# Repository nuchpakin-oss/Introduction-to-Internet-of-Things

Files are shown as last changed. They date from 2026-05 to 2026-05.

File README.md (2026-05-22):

# Introduction to Internet of Things (IoT)

โปรเจกต์นี้เป็นระบบ IoT สำหรับตรวจวัดสภาพแวดล้อมภายในห้องแบบเรียลไทม์ โดยใช้บอร์ด **ESP32** เชื่อมต่อกับเซนเซอร์ต่าง ๆ เพื่อเก็บข้อมูลและตรวจจับการเคลื่อนไหว จากนั้นสามารถนำข้อมูลไปแสดงผลหรือประยุกต์ใช้กับระบบ Smart Home ได้

## Features

* ตรวจวัดอุณหภูมิและความชื้นด้วยเซนเซอร์ DHT
* ตรวจจับการเคลื่อนไหวด้วย PIR Motion Sensor
* ตรวจจับความเข้มแสงด้วย LDR Sensor
* ใช้ RGB LED แสดงสถานะของระบบ
* ประมวลผลและควบคุมด้วย ESP32
* รองรับการพัฒนาต่อยอดสู่ระบบ IoT ผ่าน Wi-Fi

## Components Used

* ESP32 DevKit V1
* DHT11/DHT22 Sensor
* PIR Motion Sensor
* LDR Sensor
* RGB LED
* Resistors
* Breadboard & Jumper Wires

## System Overview

ระบบจะทำการอ่านค่าจากเซนเซอร์ต่าง ๆ เช่น อุณหภูมิ ความชื้น แสง และการเคลื่อนไหว แล้วส่งข้อมูลเข้าสู่ ESP32 เพื่อประมวลผล โดยสามารถแสดงสถานะผ่าน RGB LED หรือส่งข้อมูลไปยังแพลตฟอร์ม IoT สำหรับการติดตามแบบออนไลน์ได้

## Applications

* Smart Room Monitoring
* Smart Home System
* ระบบแจ้งเตือนการเคลื่อนไหว
* ระบบตรวจสอบสภาพแวดล้อมภายในอาคาร

## Circuit Diagram

ตัวอย่างการเชื่อมต่ออุปกรณ์ในโปรเจกต์



NodeRED_Dashboard

InfluxDB

Blynk_Dashboard

Blynk_Dashboard_mobile

Telegram_Alert

## Future Improvements

* เพิ่มการแสดงผลผ่าน Web Dashboard
* บันทึกข้อมูลลง Cloud Database
* แจ้งเตือนผ่าน LINE Notify หรือ Telegram
* ควบคุมอุปกรณ์ผ่าน Mobile Application

## Author

Developed for learning and experimentation in Internet of Things (IoT).

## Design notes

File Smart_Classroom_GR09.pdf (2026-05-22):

I o T P R O J E C T

# Smart Classroom Focus Monitor

## ระบบ IoT ส ำหรับตรวจสอบควำมพรอ้ มของหอ้ งเรยีน ด ้วย Edge AI + Cloud Dashboard

DHT22 | LDR | PIR | Node-RED | InfluxDB | Blynk | ThingSpeak
Smart Classroom Focus Monitor | 1

# ปัญหาและแนวคิด

### เหตุผลที่น ำ IoT มำใชใ้นหอ้ งเรยีน

## ปัญหาที่พบ

### สภาพห้องไม่เหมาะสม

ห ้องเรียนอำจร ้อน มืด หรอื ไมม่ คี นใชง้ำนแตย่ งัเปิดระบบไว ้

### ผู้ดูแลไม่เห็นสภาพ real-time

ผู้สอน/ผู้ดูแลไม่สำมำรถติดตำมสภำพห ้องเมื่ออยู่นอกห ้องได ้

### ขาดข้อมูลย้อนหล ังเพื่อปร ับปรุง

ไมม่ ขี อ้ มลู ชว่ ยวเิครำะหช์ ว่ งเวลำทสี่ ภำพหอ้ งไมเ่ หมำะสม

### แนวคิดหล ัก

### ตรวจสภาพห้อง → วิเคราะห์ความพร้อม

### → แจ้งเตือน → ควบคุมอ ัตโนม ัติ

ระบบท ำงำนวนซำ ้ เพอื่ ปรับสภำพหอ้ งใหเ้หมำะสมเสมอ

## ข ั้นตอนการท างาน

1

## Monitor — ตรวจว ัดสภาพห้อง

เซ็นเซอรเ์ก็บขอ้มลู real-time: อุณหภูมิแสง ควำมชนื้ กำร เคลื่อนไหว

2

## Analyze — วิเคราะห์ความพร้อม

ประมวลผลข ้อมูลเทียบค่ำมำตรฐำน หำควำมผิดปกติของ สภำพห ้อง

3

## Alert — แจ้งเตือนผู้สอน/ผู้ดูแล

สง่ แจง้เตอืนผำ่ นแอปหรอื dashboard เมื่อพบสภำพไม่ เหมำะสม

4

## Control — ควบคุมอุปกรณ์อ ัตโนม ัติ

สงั่ เปิด/ปิดแอร์ไฟ พัดลม ตำมเงื่อนไข เพื่อประหยัดพลังงำน

# ว ัตถุประสงค์ของระบบ

### เป้ำหมำยที่สอดคล ้องกับเกณฑ์กำรประเมิน

## เป้ าหมายหล ัก 5 ประการ

### 1 อ่ำนค่ำอุณหภูมิควำมชนื้ แสง และกำรมีคนในห ้อง

### 2 ค ำนวณ Focus Score ประเมินควำมเหมำะสมต่อกำรเรียน

### 3 เก็บข ้อมูลลง Time Series DB และแสดงกรำฟย ้อนหลัง

### 4 ควบคุม RGB LED, Buzzer และ Servo ทั้ง local/remote

### 5 แจ ้งเตือนผ่ำน Telegram เมื่อสภำพห ้องผิดปกติ

## ครอบคลุม 4 ดา้นส าคญั

### Local Dashboard

แสดงค่ำและควบคุมจำก
Node-RED Dashboard

### Remote Cloud

ดูข ้อมูลจำกภำยนอกผ่ำน
Blynk + ThingSpeak

### Edge AI

ค ำนวณ Focus Score + ตรวจ
anomaly ที่ Edge

### Notification

สง่ แจง้เตอืนผำ่ น Telegram bot

อป
ุ

# กรณท

์ ใี่
ช

้

### Sensors ≥ 2 และ Actuators ≥ 2 ตำมโจทย์

### SENSORS — ร ับข้อมูลจากสภาพแวดล้อม

## DHT22

Temperature / Humidity
วดั อณุ หภมู แิละควำมชนื้ ในหอ้ ง

## LDR / GY-302

Light
วัดควำมสว่ำงของแสงในห ้อง

## PIR

Motion
ตรวจจับกำรเคลื่อนไหวของคน

### ACTUATORS — ตอบสนองตามคา สง่ั

## RGB LED

Status Indicator
แสดงสถำนะห ้อง: เขียว/เหลือง/แดง

## Buzzer

Local Alert
สง่ เสยี งเตอื นเมอื่ พบควำมผดิ ปกติ

## Servo

Curtain Demo
จ ำลองกำรเปิด/ปิดม่ำนอัตโนมัติ

# Wiring Summary

### กำรต่อวงจรของ ESP32 กับเซน็ เซอรแ์ ละ Actuators

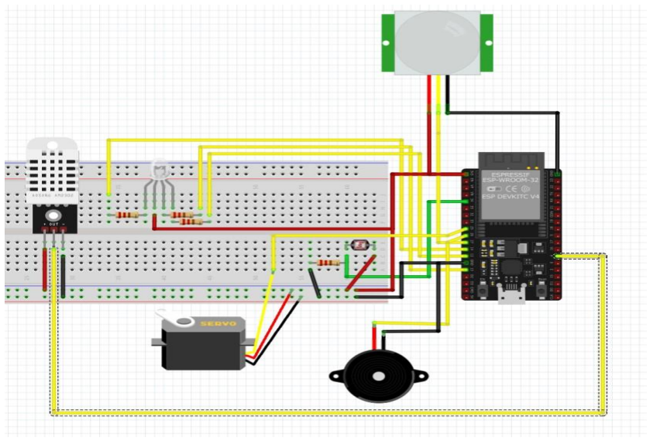
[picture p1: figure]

## การเชอื่ มตอ่ หลกั

DHT22 | GPIO 4
LDR | GPIO 34 (ADC)
PIR | GPIO 27
RGB LED | GPIO 25, 26, 33
Buzzer | GPIO 13
Servo | GPIO 14 (PWM)

ใช ้breadboard เป็ นจุดรวมกำรต่อสำย และต่อตัวต ้ำนทำนให ้ RGB LED ทุกขำ เพอื่ ป้องกนั ควำมเสยีหำย

# System Architecture

### Sensor → Edge → Database → AI → UI/Cloud → Actuator

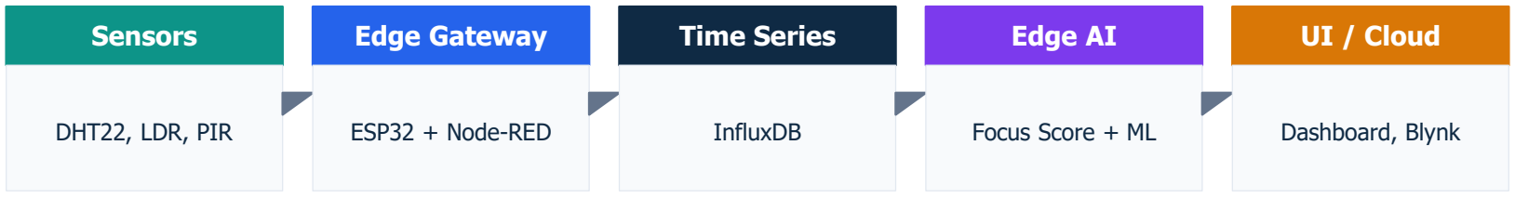
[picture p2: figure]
Sensors; DHT22, LDR, PIR; Edge Gateway; ESP32 + Node-RED; Time Series; InfluxDB; Edge AI; Focus Score + ML; UI / Cloud; Dashboard, Blynk

## Actuators: LED + Buzzer + Servo

การไหลของข้อมูล
ESP32 อ่ำนค่ำ sensor → สง่ ผำ่ น MQTT ไปยัง Node-RED → ประมวลผล Edge AI ค ำนวณ Focus Score → บันทึกลง InfluxDB และสง่ ตอ่ Dashboard/Cloud → สง่ ค ำสงั่ กลบั ไปควบคมุ Actuators

# Flowchart การท างาน

### ล ำดับขนั้ หลักของระบบตัง้แตร่ ับขอ้มลู ถงึสง่ ออก

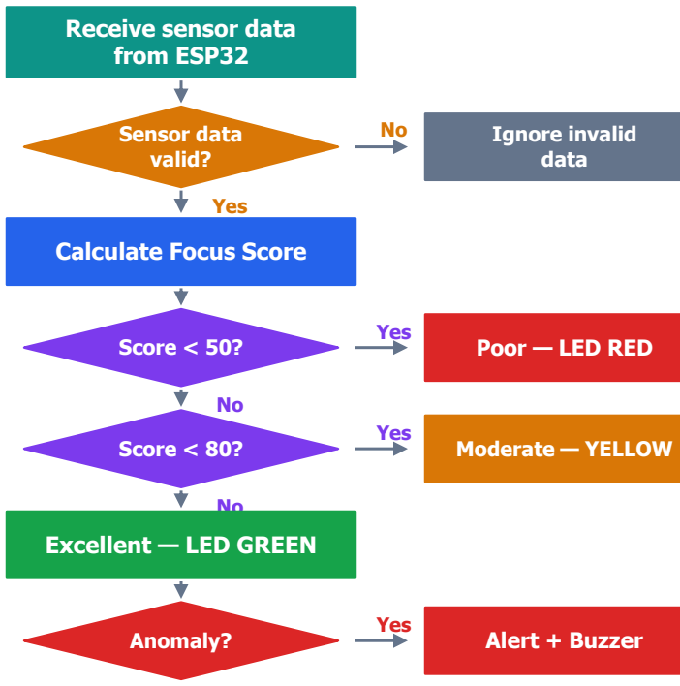
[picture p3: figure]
Receive sensor data from ESP32; Sensor data valid?; Ignore invalid; data; Yes; Calculate Focus Score; Score < 50?; Poor — LED RED; Score < 80?; Moderate — YELLOW; Excellent — LED GREEN; Anomaly?; Alert + Buzzer

## ข ั้นตอนหล ักของระบบ

1

ร ับข้อมูลจาก ESP32

Node-RED รับ payload จำก MQTT

2

ตรวจสอบ valid

ถ ้ำค่ำผิด → ข ้ำม payload ถัดไป

3

Calculate Focus Score
แปลง temp + light + motion เป็ น 0–100

4

Classify Status
Poor / Moderate / Excellent + เปลยี่ นสีLED

5

Anomaly Detection

Temp > 30°C หรือมืด แต่มีคน → alert

6

Edge AI ท านายแนวโน้ม

ใช ้5 ค่ำหลัง predict trend

7

สง่ ออก

Dashboard / InfluxDB / Cloud / Telegram

# Node-RED Flow

### Edge gateway สำ หรับรับขอ้มลู ประมวลผลและสง่ ตอ่

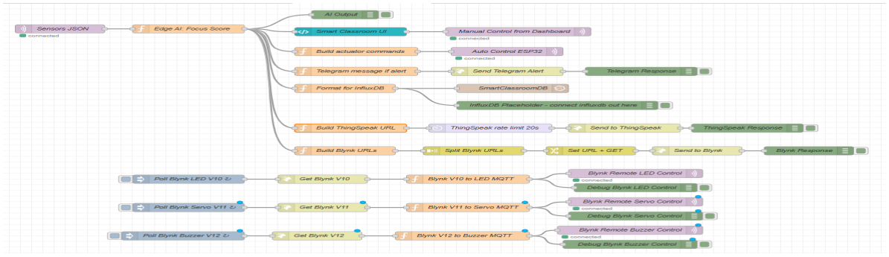
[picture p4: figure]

Input

■ | รับ Sensors JSON ผ่ำน MQTT
■ | สง่ เขำ้ Edge AI function เพื่อค ำนวณ
Focus Score และตรวจ anomaly

Process

■ Build actuator commands → สง่ กลับให้ ESP32 ท ำงำน auto/manual
■ Format ข ้อมูลเพื่อเก็บลง InfluxDB

Output

■ สง่ ขอ้มลู ไป ThingSpeak + Blynk (cloud dashboard)
■ Telegram alert เมื่อพบควำมผิดปกติ

# Time Series Database

### InfluxDB สำ หรับเก็บขอ้มลู ยอ้นหลังเพอื่ วเิครำะห์

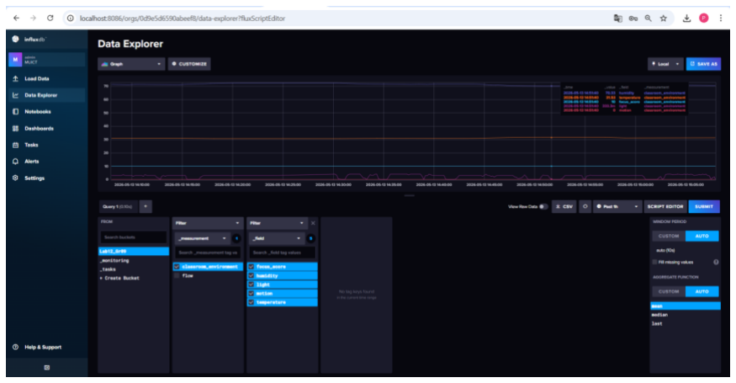
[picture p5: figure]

## โครงสร้างข้อมูล

Database | classroom_iot
Measurement | classroom_environment
Fields | temperature, humidity, light, motion, focus_score
Window | 10 วินำทีต่อจุด (auto)

## ท าไมต้อง Time Series DB?

บ ันทึกข้อมูลตามเวลา
เก็บค่ำทุกตัวพร ้อม timestamp อัตโนมัติ

Query รวดเร็ว
ดงึขอ้มลู ชว่ งเวลำทตี่ อ้ งกำรไดท้ นั ที

วิเคราะห์ย้อนหล ัง
หำชว่ งเวลำทหี่ อ้ งไมเ่ หมำะสมเพอื่ ปรับปรุง

# Installation & Database Setup

### กำรติดตั้งและตั้งค่ำ Node-RED + InfluxDB

## ข ั้นตอนการติดต ั้ง

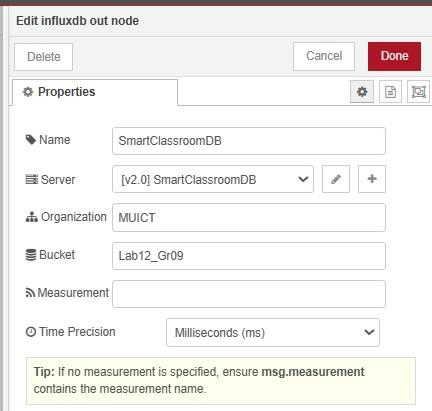
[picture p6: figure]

1

ติดต ั้ง Node.js + Node-RED

npm install -g node-red

2

เพิ่ม Dashboard module

npm install node-red-dashboard

3

เพิ่ม InfluxDB nodes

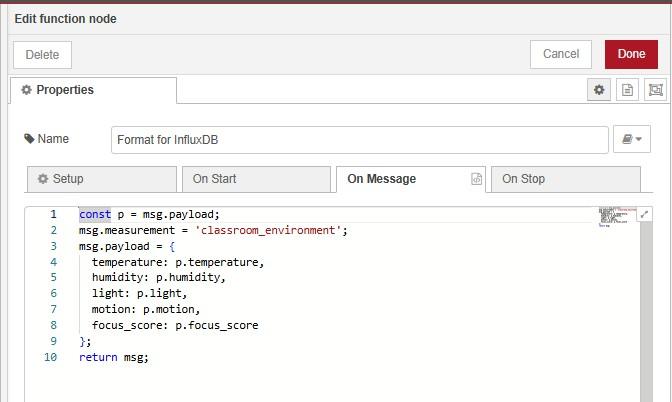
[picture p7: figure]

npm install node-red-contrib-influxdb

4

ติดต ั้ง InfluxDB v2

Docker หรือ Local installer

5

สร้าง Bucket ใน InfluxDB

Org: MUICT / Bucket: Lab12_Gr09

## Node-RED InfluxDB Configuration

influxdb out node

Server: SmartClassroomDB
Organization: MUICT
Bucket: Lab12_Gr09
Time Precision: Milliseconds

Format function

ก ำหนด measurement และ
payload กอ่ นสง่ เขำ้ InfluxDB

# Node-RED Function Nodes Setup

## 1. Edge AI: Focus Score

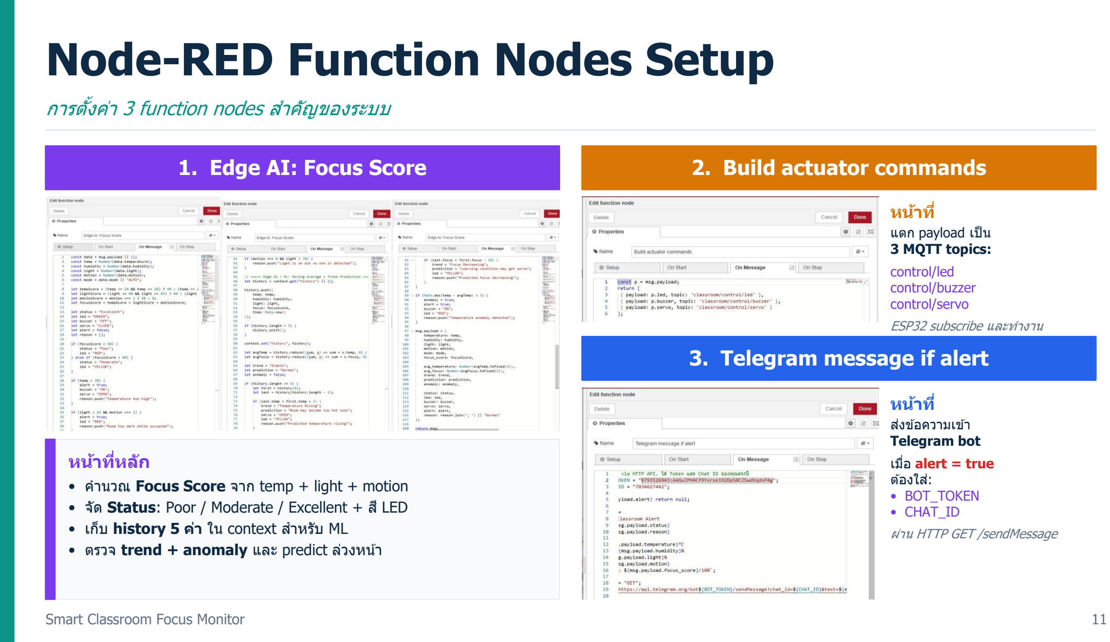
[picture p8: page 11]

### กำรตั้งค่ำ 3 function nodes สำ คัญของระบบ

หน้าที่หล ัก

- ค ำนวณ Focus Score จำก temp + light + motion
- จัด Status: Poor / Moderate / Excellent + สีLED
- เก็บ history 5 ค่า ใน context ส ำหรับ ML
- ตรวจ trend + anomaly และ predict ล่วงหน้ำ

## 2. Build actuator commands

หน้าที่

แตก payload เป็ น

### 3 MQTT topics:

control/led
control/buzzer
control/servo

ESP32 subscribe และท ำงำน

## 3. Telegram message if alert

หน้าที่

สง่ ขอ้ควำมเขำ้
Telegram bot
เมื่อ alert = true
ตอ้ งใส:่
- BOT_TOKEN
- CHAT_ID

ผ่ำน HTTP GET /sendMessage

# Cloud Connection Setup

### วธิเีชอื่ มตอ่ Blynk + ThingSpeak จำก Node-RED

### Node-RED Flow สง่ ขอ้ มลู ขนึ้ Cloud

หล ักการท างาน

function node สร ้ำง URL แลว้สง่ ผำ่ น HTTP request ไป cloud — ThingSpeak จ ำกัด 20 วินำที/ครั้ง, Blynk สง่ ทลี ะ field

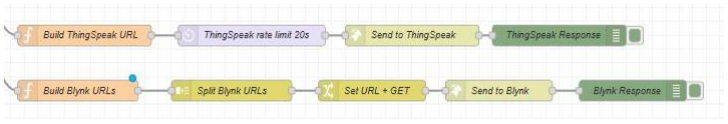
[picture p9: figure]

### ThingSpeak — สง่ ทกุ field ใน URL เดียว

### 1 สร ้ำง Channel + เพิ่ม 5 fields

### 2 คัดลอก Write API Key

### 3 ใส่ key ใน function (KEY)

### 4 สง่ HTTP GET request

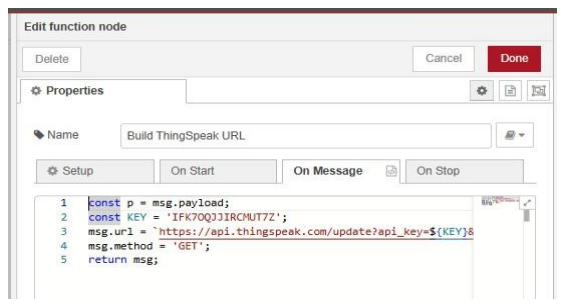
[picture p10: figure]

api_key + field1..field5 รวมใน URL เดียว

### Blynk — สง่ แยกทลี ะ Virtual Pin (V0–V4)

1

สร ้ำง Template +
Device

### 2 ตั้ง Datastream V0–V4

### 3 คัดลอก Auth Token

4

ใส่ TOKEN + map
V0..V4

### 5 Split URLs → สง่ ทลี ะตัว

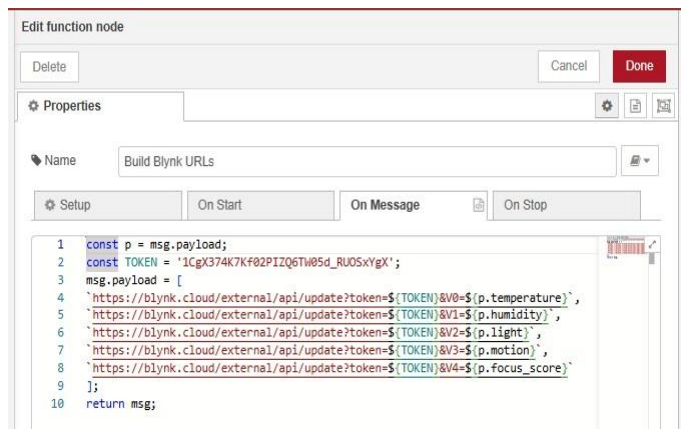
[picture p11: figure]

token + V0..V4 สง่ แยก URL — Set URL + GET ทีละตัว

# Edge AI / ML Logic

### Focus Score + Anomaly Detection แบบง่ำยที่ Edge

## องค์ประกอบของ Focus Score (เต็ม 100 คะแนน)

Temperature | 40

/100

ชว่ งทไี่ ดค้ ะแนนเต็ม
24–28 °C

ตรวจวัดทุกรอบ

Light | 40

/100

ชว่ งทไี่ ดค้ ะแนนเต็ม
40–85 %

ตรวจวัดทุกรอบ

Motion | 20

/100

ชว่ งทไี่ ดค้ ะแนนเต็ม
Detected

ตรวจวัดทุกรอบ

## Status Mapping จาก Focus Score

## Excellent

80–100

พรอ้ มสำ หรับกำรเรยี น

## Moderate

50–79

ควรปรับสภำพห ้อง

## Poor

< 50

ไม่เหมำะกับกำรเรียน

ตัวอย่ำง anomaly: temp > 30°C หรือ light < 25% ขณะมีคนอยู่ → แจ ้งเตือนทันที

# Focus Score Calculation

### แปลงค่ำจำก sensor เป็ นคะแนนสภำพห ้องเรียนแบบ real-time

### Input

Temperature
Humidity
Light
Motion

Temp Score
24–28°C = 40 | 22–30°C = 25
| อื่น ๆ = 5

Light Score
40–85% = 40 | ≥25% = 25 |
อื่น ๆ = 5

Motion Score
motion=1 → 20 | motion=0 →
0

→

### Focus Score

=

temp +
light +
motion

→

### Status

Excellent: 80–100
Moderate: 50–79
Poor: < 50

## ผลล ัพธ์→ ควบคุม Actuator

ค ำนวณบน Edge (Node-RED) จึงตอบสนองได ้รวดเร็ว ไม่ต ้องรอ cloud

# Anomaly Detection Rules

### เงื่อนไขแจ ้งเตือนและกำรตอบสนองของ actuator ที่ Edge

IF | Temperature > 30°C
THEN | Alert ON + Buzzer ON + Servo OPEN

เมอื่ หอ้ งรอ้นเกนิจะสง่ เสยี งเตอื นและเปิดมำ่ นเพอื่ ระบำยควำมรอ้น

IF | Light < 25% และ Motion = 1
THEN | Alert ON + LED RED + Reason: too dark

เมื่อมีคนในห ้องแต่แสงน้อย จะเตือนให ้เปิดไฟทันที

IF | Motion = 0 และ Light > 70%
THEN | Reason only: Light is on but no one detected

เมื่อห ้องว่ำงแต่ไฟยังเปิดอยู่ จะแจ ้งเตือนเพื่อประหยัดพลังงำน

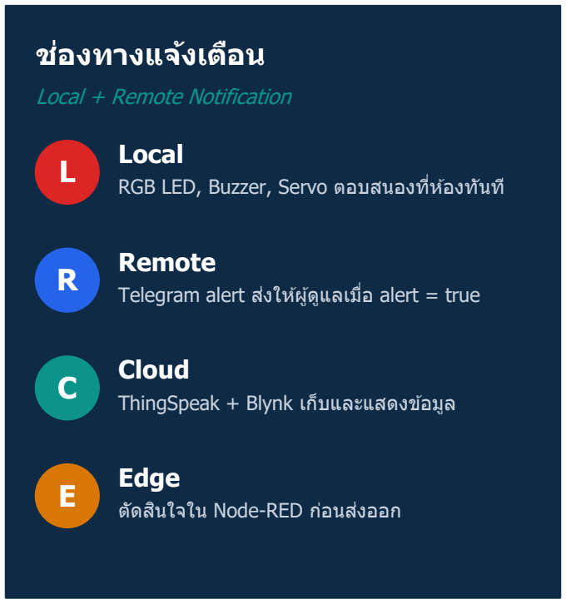
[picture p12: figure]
ชอ่ งทางแจง้เตอืน; Local + Remote Notification; Local; Remote; Cloud; ThingSpeak + Blynk เก็บและแสดงข ้อมูล; Edge; ตัดสนิ ใจใน Node-RED กอ่ นสง่ ออก

RGB LED, Buzzer, Servo ตอบสนองที่ห ้องทันที

Telegram alert สง่ ใหผ้ ดู้ แู ลเมอื่ alert = true

# Edge ML: Trend & Anomaly

### Moving Average + Trend Prediction ด ้วยข ้อมูลย ้อนหลัง 5 ค่ำ

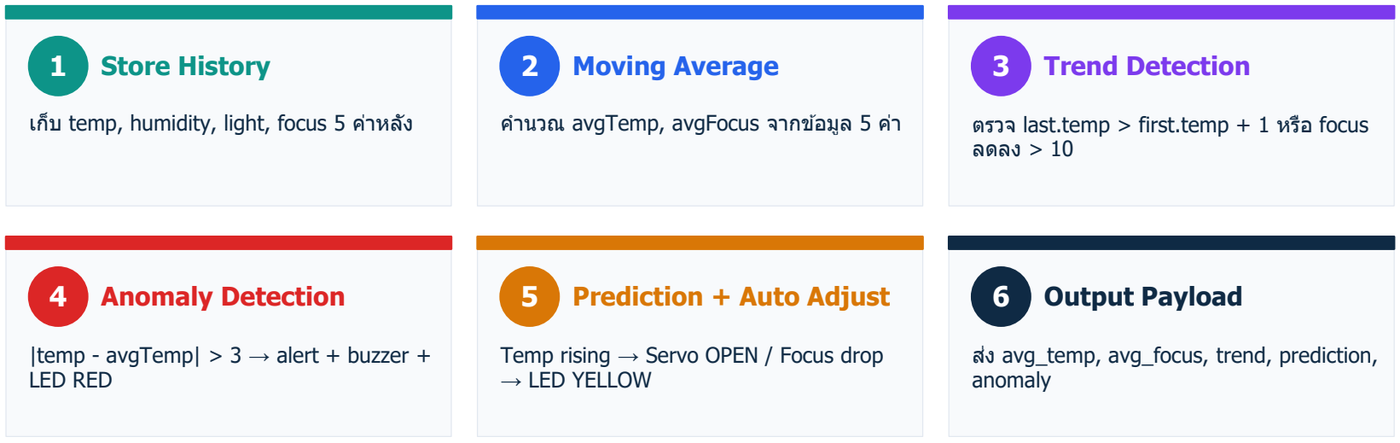
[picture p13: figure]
1 Store History; 2 Moving Average; 3 Trend Detection; ลดลง > 10; 4 Anomaly Detection; |temp - avgTemp| > 3 → alert + buzzer + LED RED; 5 Prediction + Auto Adjust; Temp rising → Servo OPEN / Focus drop → LED YELLOW; 6 Output Payload; สง่ avg_temp, avg_focus, trend, prediction, anomaly

เก็บ temp, humidity, light, focus 5 ค่ำหลัง ค ำนวณ avgTemp, avgFocus จำกข ้อมูล 5 ค่ำ ตรวจ last.temp > first.temp + 1 หรือ focus

ท าไมต้อง Moving Average + Trend Prediction?

ลดสญั ญำณรบกวนจำกคำ่ ผดิเพยี้ นชวั่ ครำว และท ำนำยแนวโน้มล่วงหน้ำ เชน่ ห ้องก ำลังจะร ้อน → เปิดม่ำนก ่อนถึงจุด 30°C

# Remote Cloud Platforms

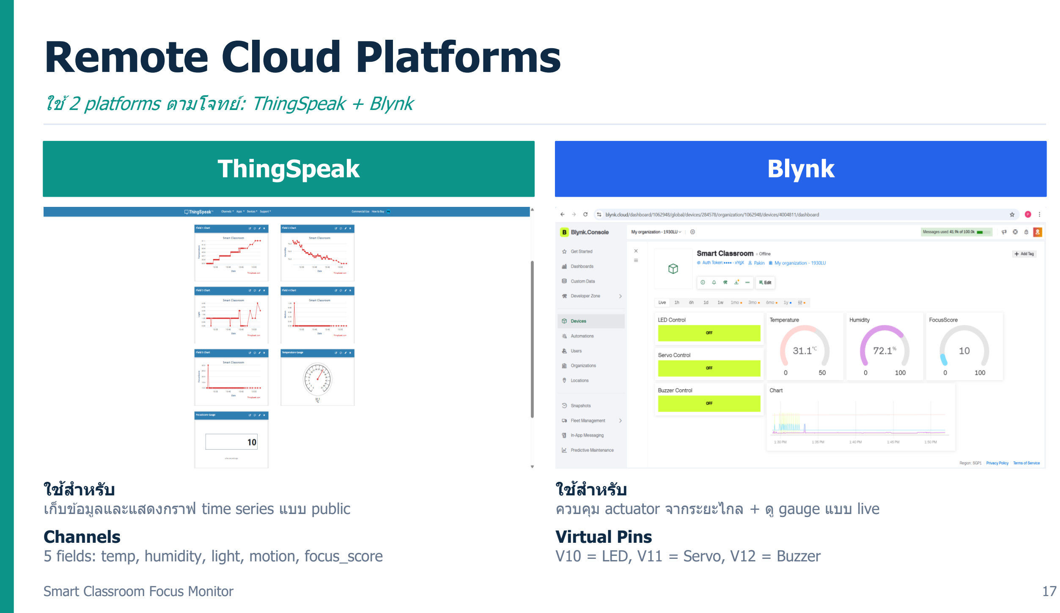
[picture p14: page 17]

### ใช ้2 platforms ตำมโจทย์: ThingSpeak + Blynk

## ThingSpeak

ใชส้ าหรบั
เก็บข ้อมูลและแสดงกรำฟ time series แบบ public

Channels
5 fields: temp, humidity, light, motion, focus_score

## Blynk

ใชส้ าหรบั
ควบคุม actuator จำกระยะไกล + ดูgauge แบบ live

Virtual Pins
V10 = LED, V11 = Servo, V12 = Buzzer

# Local Dashboard Design

### Node-RED Dashboard สำ หรับใชง้ำนใน local network

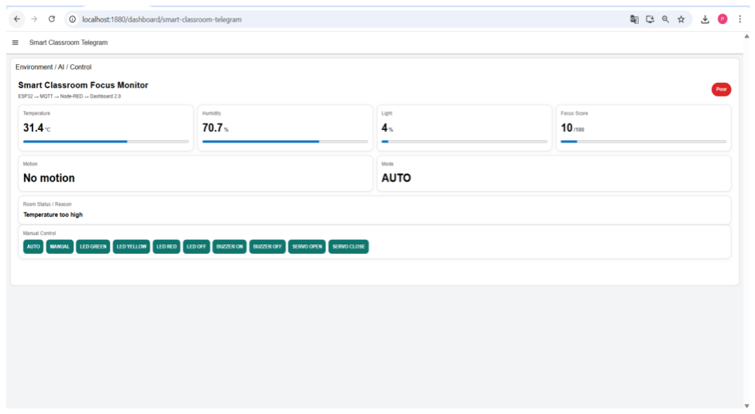
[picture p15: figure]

## Widgets ในแดชบอร์ด

Temperature Gauge | Humidity Gauge
Light Gauge | Focus Score + Status
Temp/Light Charts | Manual Controls

## คุณสมบ ัติเด่น

# Notifications

### แจ ้งเตือนทั้ง local และ remote ผ่ำน Telegram

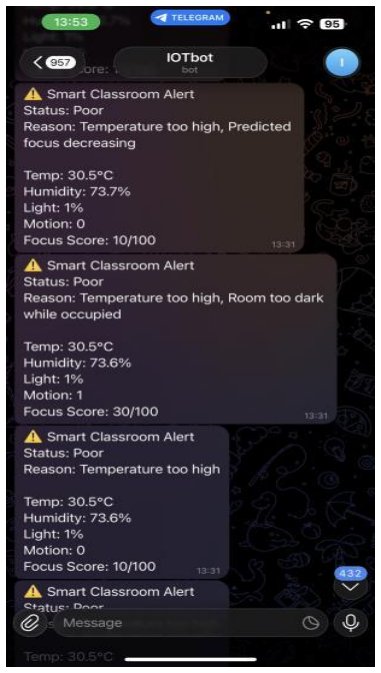
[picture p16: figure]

## เสน้ ทางการแจง้เตอืน

### Condition

Temp > 30°C
Light < 25%
Motion = 0
(บำงเงื่อนไข)

→

→

Local Alert

RGB LED + Buzzer

Remote Alert

Telegram Bot

→

### User / Teacher

รับกำรแจ ้งเตือน
บนมือถือ
และตอบสนอง

### ข้อมูลใน Telegram alert

Status: Poor / Moderate / Excellent
Reason: เชน่ Temperature too high, Room too dark Values: Temp, Humidity, Light, Motion, Focus Score Prediction: หำก trend แสดงให ้เห็นว่ำจะแย่ลง

# ปัญหาและแนวทางแก้ไข

### ขอ้จ ำกัดของโครงงำนและวธิที ใี่ ชแ้กป้ ัญหำ

### ค ่า Sensor แกว่งและไม่นิ่ง

ปัญหา | ค่ำ LDR/DHT22 มีnoise และผันผวนเร็วเกินไป
วิธีแก้ | ใช้Moving Average 5 ค่า ลดสญั ญาณรบกวน

### การเชอื่ มตอ่ MQTT หลุดบางคร ั้ง

ปัญหา | WiFi ในห ้องเรียนอำจไม่เสถียร ท ำใหข้ อ้มลู ขำดชว่ ง
วิธีแก้ | ESP32 ท า auto-reconnect และ retry ทุก 5 วินาที

### Edge AI ตดัสนิ ใจผดิ เมอื่ คนแคเ่ ดนิ ผา่ น

ปัญหา | PIR ตรวจจับกำรเคลอื่ นไหวระยะสนั้ เป็น motion = 1
วิธีแก้ | เพิ่มเงื่อนไข motion ต้อง = 1 ต่อเนื่อง 2 รอบขนึ้ ไป

### Telegram alert สง่ ซ า้ๆ มากเกินไป

ปัญหา | เงื่อนไขเดิมท ำให ้แจ ้งเตือนทุกรอบที่ค่ำยังผิด
วิธีแก้ | เพิ่ม cooldown 60 วินาทีหล ังจากแจ้งคร ั้งล่าสุด

ระบบผา่ นการทดสอบและพรอ้ มสา หรบัการ Demo

# ประโยชนแ

์

# ละการประยก

ุ

# ตใ์ช

้

### Project สำมำรถน ำไปปรับใชใ้นงำนหลำยรปู แบบ

## ประโยชน์หล ัก

✓

### ลดการใชพ้ ลงังาน

ปิดไฟ/แอร์อัตโนมัติเมื่อห ้องว่ำง

✓

### เพมิ่ ประสทิ ธภิ าพการเรยีน

ปรับสภำพห ้องให ้เหมำะสมตลอดเวลำ

✓

### ผู้ดูแลมองเห็นภาพรวม

ติดตำมหลำยห ้องพร ้อมกันจำกที่ใดก็ได ้

✓

### เก็บขอ้ มลู เชงิสถติ ิ

น ำไปปรับปรุงตำรำงเรียนและพลังงำนในภำยหลัง

## การประยกุ ตใ์ชก้ บังานอนื่

### Smart Office

ตรวจสภำพห ้องประชุมและออฟฟิศ

### Smart Library

วัดอุณหภูมิ+ จ ำนวนคน เพื่อจัดกำรแอร์

### Smart Lab

เฝ้ำระวังสภำพแวดล ้อมในห ้องวิจัย

### Smart Greenhouse

ปรับใชก้บั กำรเกษตรในเรอื นปลกู พชื เพยี งเปลยี่ นเซ็นเซอรแ์ ละเงอื่ นไข ก็น าสถาปตั ยกรรมไปใชก้ บั โดเมนอนื่ ไดท้ นัที

# การใช

# ้AI ชว

่

# ยในการออกแบบ

### ระบกุ ำรใช ้AI ในกระบวนกำรพัฒนำโครงงำน

## สว่ นที่AI ชว่ ยในการออกแบบ

ออกแบบสถาปัตยกรรมระบบ

ใช ้AI ชว่ ยวำง flow ของ ESP32 | Node-RED | Cloud

เขียนโค้ด ESP32 และ Node-RED

ใช ้AI ชว่ ย generate code ส ำหรับ MQTT และ function nodes

ออกแบบ Focus Score และ rules
ปรึกษำ AI เพื่อจัดเกณฑ์คะแนนและเงื่อนไข anomaly

## หลกัการใช้AI อย่างมีความร ับผิดชอบ

1

ตรวจสอบโค ้ดที่ AI สรำ้งทกุ บรรทดั กอ่ นใชง้ำนจรงิ

2

ทดสอบ Focus Score กับข ้อมูลจริงในห ้องเรียน เพื่อปรับเกณฑ์ ให ้เหมำะสม

3

ปรับ prompt และเงื่อนไข AI ให ้สอดคล ้องกับโจทย์ที่ได ้รับ

4

ใช ้AI เป็นผชู้ ว่ ย ไมใ่ ชผ่ ตู้ ดั สนิ ใจ — นักพัฒนำยังต ้องเข ้ำใจ ระบบเองทั้งหมด

AI เป็ นเพียงเครื่องมือ — การออกแบบและการตดัสนิ ใจสดุ ทา้ยคอืของผพู้ ฒั นา

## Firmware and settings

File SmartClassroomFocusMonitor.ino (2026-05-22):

/*
  Project: Smart Classroom Focus Monitor
  Board: ESP32
  References:
  - DHT sensor library by Adafruit
  - PubSubClient by Nick O'Leary
  - ESP32Servo library
  - Arduino ESP32 WiFi examples

  What this code does:
  1) Reads DHT22, LDR, and PIR sensors
  2) Publishes sensor data as JSON to MQTT topic: classroom/sensors
  3) Subscribes to MQTT control topics for RGB LED, buzzer, servo, and mode
  4) Supports both AUTO logic from Node-RED and MANUAL control from dashboard/cloud
*/

#include <WiFi.h>
#include <PubSubClient.h>
#include <DHT.h>
#include <ESP32Servo.h>

// ================= USER CONFIG =================
const char* WIFI_SSID     = "SirPakin";
const char* WIFI_PASSWORD = "12345689";

// If Node-RED/Mosquitto is on your laptop, use laptop IP, e.g. 192.168.1.10
const char* MQTT_SERVER = "broker.emqx.io";
const int   MQTT_PORT   = 1883;
const char* MQTT_CLIENT_ID = "esp32_smart_classroom";

// ================= PIN CONFIG =================
#define DHT_PIN      4
#define DHT_TYPE     DHT22
#define LDR_PIN      34     // ADC input only
#define PIR_PIN      27
#define LED_R_PIN    14
#define LED_G_PIN    12
#define LED_B_PIN    13
#define BUZZER_PIN   26
#define SERVO_PIN    25

// ================= MQTT TOPICS =================
const char* TOPIC_SENSOR       = "classroom/sensors";
const char* TOPIC_LED          = "classroom/control/led";      // RED/GREEN/BLUE/YELLOW/OFF
const char* TOPIC_BUZZER       = "classroom/control/buzzer";   // ON/OFF
const char* TOPIC_SERVO        = "classroom/control/servo";    // OPEN/CLOSE/0-180
const char* TOPIC_MODE         = "classroom/control/mode";     // AUTO/MANUAL
const char* TOPIC_HEARTBEAT    = "classroom/status/esp32";

WiFiClient espClient;
PubSubClient mqtt(espClient);
DHT dht(DHT_PIN, DHT_TYPE);
Servo curtainServo;

unsigned long lastPublish = 0;
const unsigned long PUBLISH_INTERVAL_MS = 3000;
String currentMode = "AUTO";

void setRGB(bool r, bool g, bool b) {
  digitalWrite(LED_R_PIN, r ? HIGH : LOW);
  digitalWrite(LED_G_PIN, g ? HIGH : LOW);
  digitalWrite(LED_B_PIN, b ? HIGH : LOW);
}

void setLEDColor(String color) {
  color.toUpperCase();
  if (color == "RED") setRGB(true, false, false);
  else if (color == "GREEN") setRGB(false, true, false);
  else if (color == "BLUE") setRGB(false, false, true);
  else if (color == "GREEN") setRGB(true, true, false);
  else if (color == "CYAN") setRGB(false, true, true);
  else if (color == "MAGENTA") setRGB(true, false, true);
  else setRGB(false, false, false);
}

void setBuzzer(String state) {
  state.toUpperCase();
  digitalWrite(BUZZER_PIN, state == "ON" ? HIGH : LOW);
}

void setServo(String command) {
  command.toUpperCase();
  if (command == "OPEN") curtainServo.write(90);
  else if (command == "CLOSE") curtainServo.write(0);
  else {
    int angle = command.toInt();
    if (angle >= 0 && angle <= 180) curtainServo.write(angle);
  }
}

void mqttCallback(char* topic, byte* payload, unsigned int length) {
  String msg = "";
  for (unsigned int i = 0; i < length; i++) msg += (char)payload[i];
  String t = String(topic);

  if (t == TOPIC_LED) setLEDColor(msg);
  else if (t == TOPIC_BUZZER) setBuzzer(msg);
  else if (t == TOPIC_SERVO) setServo(msg);
  else if (t == TOPIC_MODE) {
    msg.toUpperCase();
    if (msg == "AUTO" || msg == "MANUAL") currentMode = msg;
  }
}

void connectWiFi() {
  Serial.print("Connecting WiFi");
  WiFi.mode(WIFI_STA);
  WiFi.begin(WIFI_SSID, WIFI_PASSWORD);
  while (WiFi.status() != WL_CONNECTED) {
    delay(500);
    Serial.print(".");
  }
  Serial.println();
  Serial.print("WiFi connected. IP: ");
  Serial.println(WiFi.localIP());
}

void connectMQTT() {
  while (!mqtt.connected()) {
    Serial.print("Connecting MQTT...");
    if (mqtt.connect(MQTT_CLIENT_ID)) {
      Serial.println("connected");
      mqtt.subscribe(TOPIC_LED);
      mqtt.subscribe(TOPIC_BUZZER);
      mqtt.subscribe(TOPIC_SERVO);
      mqtt.subscribe(TOPIC_MODE);
      mqtt.publish(TOPIC_HEARTBEAT, "ESP32 online");
    } else {
      Serial.print("failed rc=");
      Serial.print(mqtt.state());
      Serial.println(" retry in 3s");
      delay(3000);
    }
  }
}

int readLightPercent() {
  int raw = analogRead(LDR_PIN);        // 0-4095
  int percent = map(raw, 0, 4095, 0, 100);
  // Depending on your voltage divider wiring, value may be inverted.
  // If light/dark is reversed, replace the line above with: map(raw, 0, 4095, 100, 0)
  return constrain(percent, 0, 100);
}

void publishSensors() {
  float temp = dht.readTemperature();
  float hum  = dht.readHumidity();
  int lightPercent = readLightPercent();
  int motion = digitalRead(PIR_PIN);

  if (isnan(temp) || isnan(hum)) {
    Serial.println("DHT read failed");
    return;
  }

  char payload[256];
  snprintf(payload, sizeof(payload),
           "{\"temperature\":%.2f,\"humidity\":%.2f,\"light\":%d,\"motion\":%d,\"mode\":\"%s\"}",
           temp, hum, lightPercent, motion, currentMode.c_str());

  mqtt.publish(TOPIC_SENSOR, payload);
  Serial.println(payload);
}

void setup() {
  Serial.begin(115200);
  dht.begin();

  pinMode(PIR_PIN, INPUT);
  pinMode(LED_R_PIN, OUTPUT);
  pinMode(LED_G_PIN, OUTPUT);
  pinMode(LED_B_PIN, OUTPUT);
  pinMode(BUZZER_PIN, OUTPUT);

  setLEDColor("OFF");
  setBuzzer("OFF");

  curtainServo.attach(SERVO_PIN);
  curtainServo.write(0);

  connectWiFi();
  mqtt.setServer(MQTT_SERVER, MQTT_PORT);
  mqtt.setCallback(mqttCallback);
}

void loop() {
  if (WiFi.status() != WL_CONNECTED) connectWiFi();
  if (!mqtt.connected()) connectMQTT();
  mqtt.loop();

  if (millis() - lastPublish >= PUBLISH_INTERVAL_MS) {
    lastPublish = millis();
    publishSensors();
  }
}
